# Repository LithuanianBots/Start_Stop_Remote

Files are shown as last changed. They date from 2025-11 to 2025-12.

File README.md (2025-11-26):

# Start_Stop_Remote

Start_Stop_Remote is a compact infrared remote designed for use with the MINI SUMO kit mainboard. It provides a small, robust controller for starting and stopping matches and is built with readily-available components to make assembly and sourcing easy.

Key features
- Remote uses IR SMD LEDs for a low-profile, reliable IR transmitter.
- Remote has additional IR LED footprints for standard 5 mm LEDs if you prefer through-hole components.
- PCB size: 80 mm x 40 mm — compact and easy to fit in a small enclosure.
- All free ATmega328 pins are routed to accessible solder pads so you can expand or repurpose the board.
- Most parts come from the LCSC basic parts library to simplify procurement.

Files and docs
- Full schematic and 3d files are available in the Docs folder:
  - Docs/Start_Stop_Remote.pdf
  - Docs/Start_Stop_Remote.step

Gallery (Top and Bottom views)
| TOP view | BOT view |
|---|---|
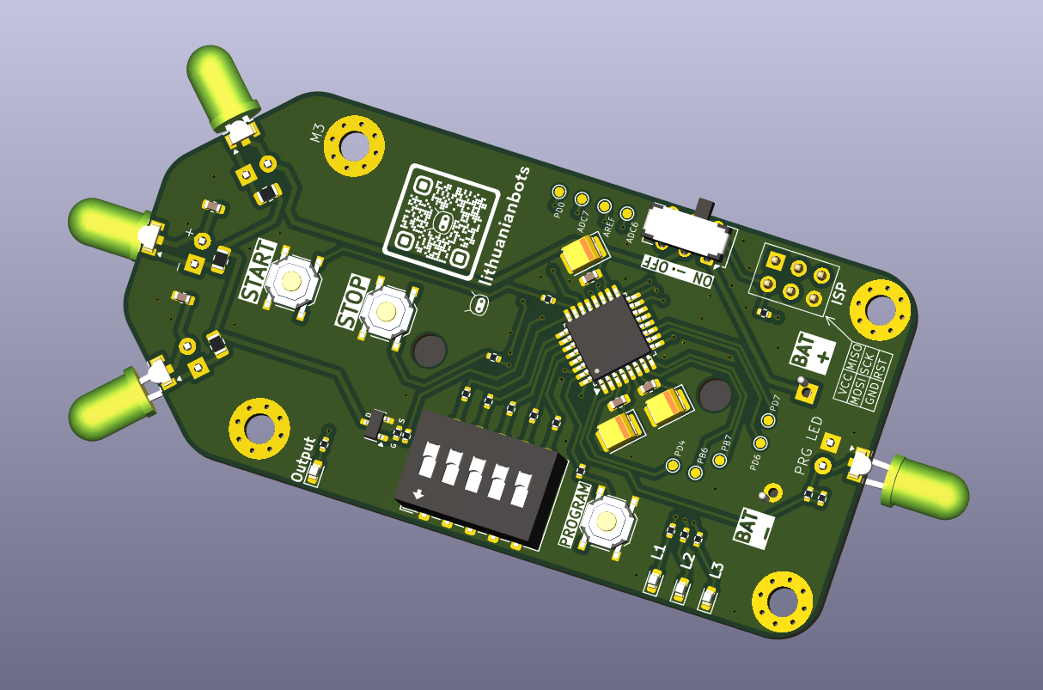
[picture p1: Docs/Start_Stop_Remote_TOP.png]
Start_Stop_Remote TOP
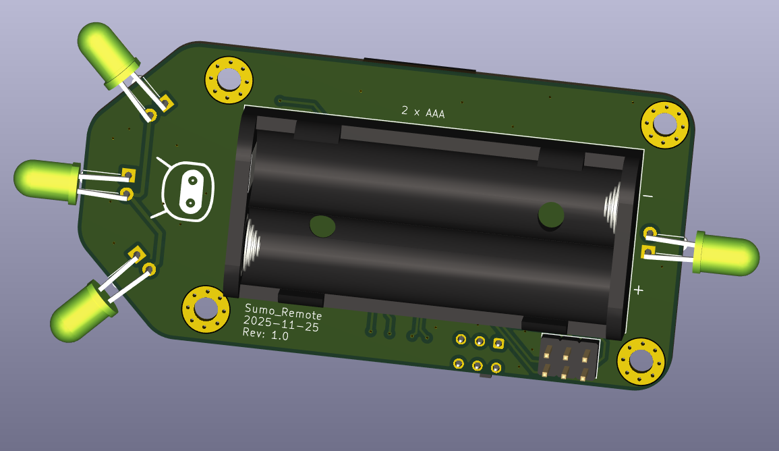
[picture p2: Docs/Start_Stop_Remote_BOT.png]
Start_Stop_Remote BOT
|  |  |

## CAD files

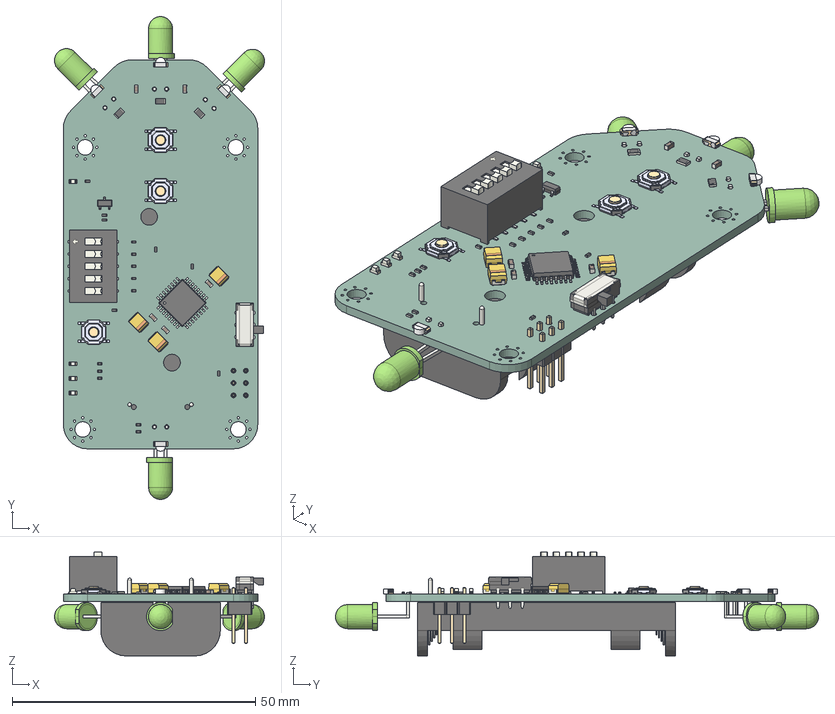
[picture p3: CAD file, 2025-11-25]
Docs/Start_Stop_Remote.step
43.2 x 99.3 x 21.4 mm
LTST-S326KGJRKT x 4
R_0402_1005Metric x 17
TS-1187A-B-A-B x 3
CP_EIA-3528-21_Kemet-B x 3
SW_DIP_SPSTx05_Slide_9.78x14.88mm_W8.61mm_P2.54mm
LED_0603_1608Metric x 4
SW_CK_JS202011AQN_DPDT_Angled
C_0603_1608Metric x 5
R_0805_2012Metric x 3
LQFP-32_7x7mm_P0.8mm
SOT-23
LED_D5.0mm_Horizontal_O6.35mm_Z3.0mm x 4
PinHeader_2x03_P2.54mm_Vertical
BatteryHolder_Keystone_2468_2xAAA
Start_Stop_Remote_PCB

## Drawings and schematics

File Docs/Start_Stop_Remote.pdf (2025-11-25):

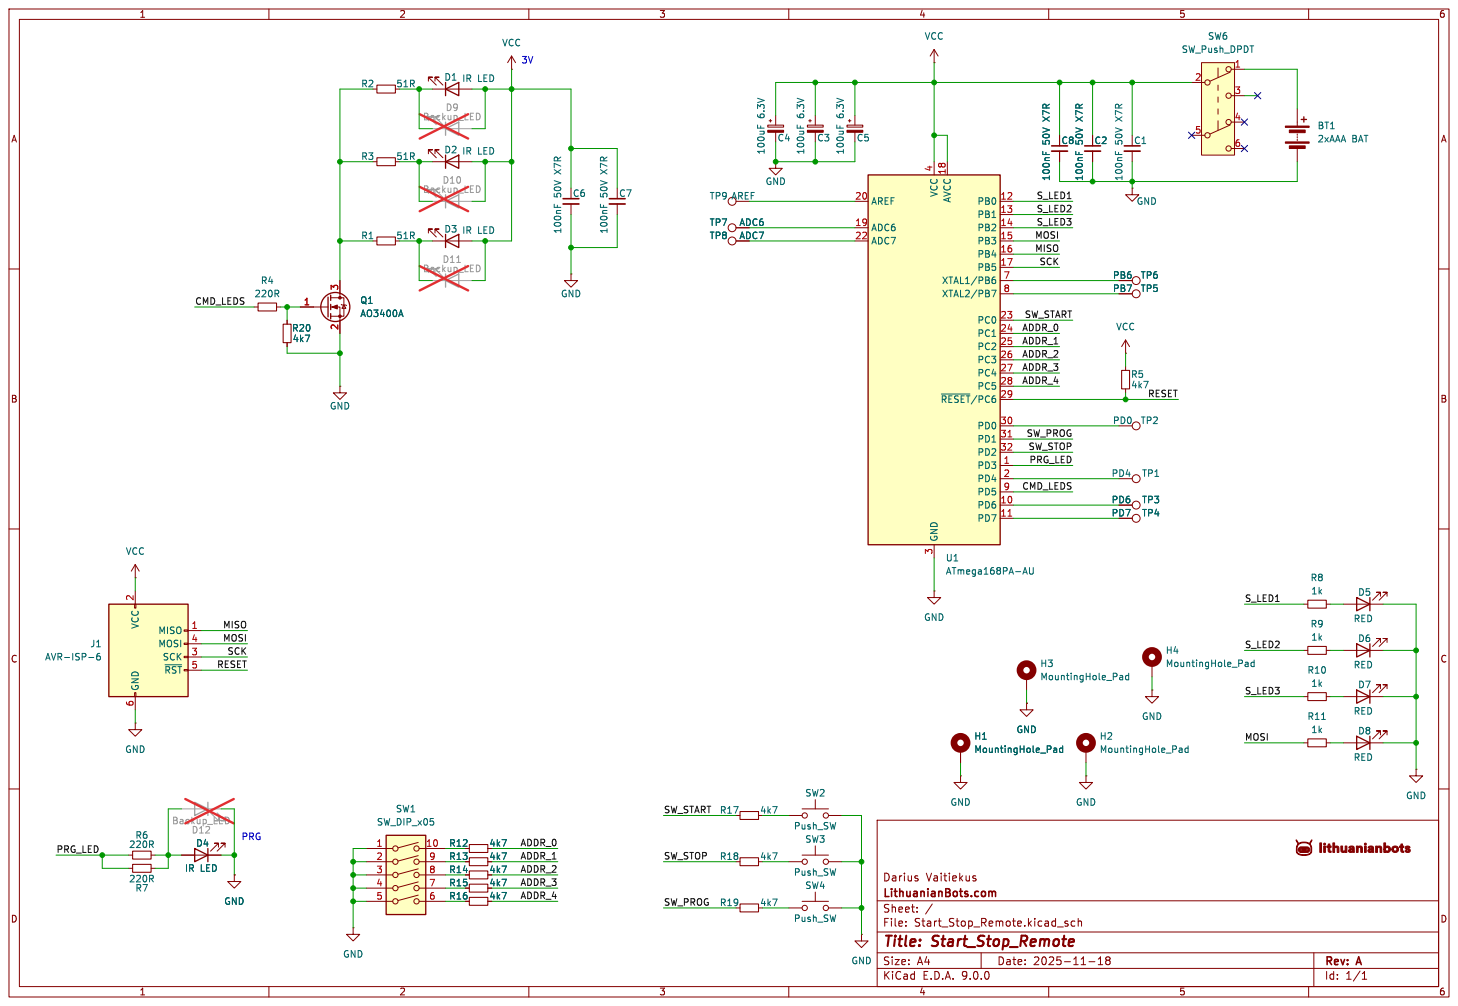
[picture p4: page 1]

6 MISO 1 MOSI 4 SCK 3 ~{RST}5

File: Start_Stop_Remote.kicad_sch Sheet: / LithuanianBots.com

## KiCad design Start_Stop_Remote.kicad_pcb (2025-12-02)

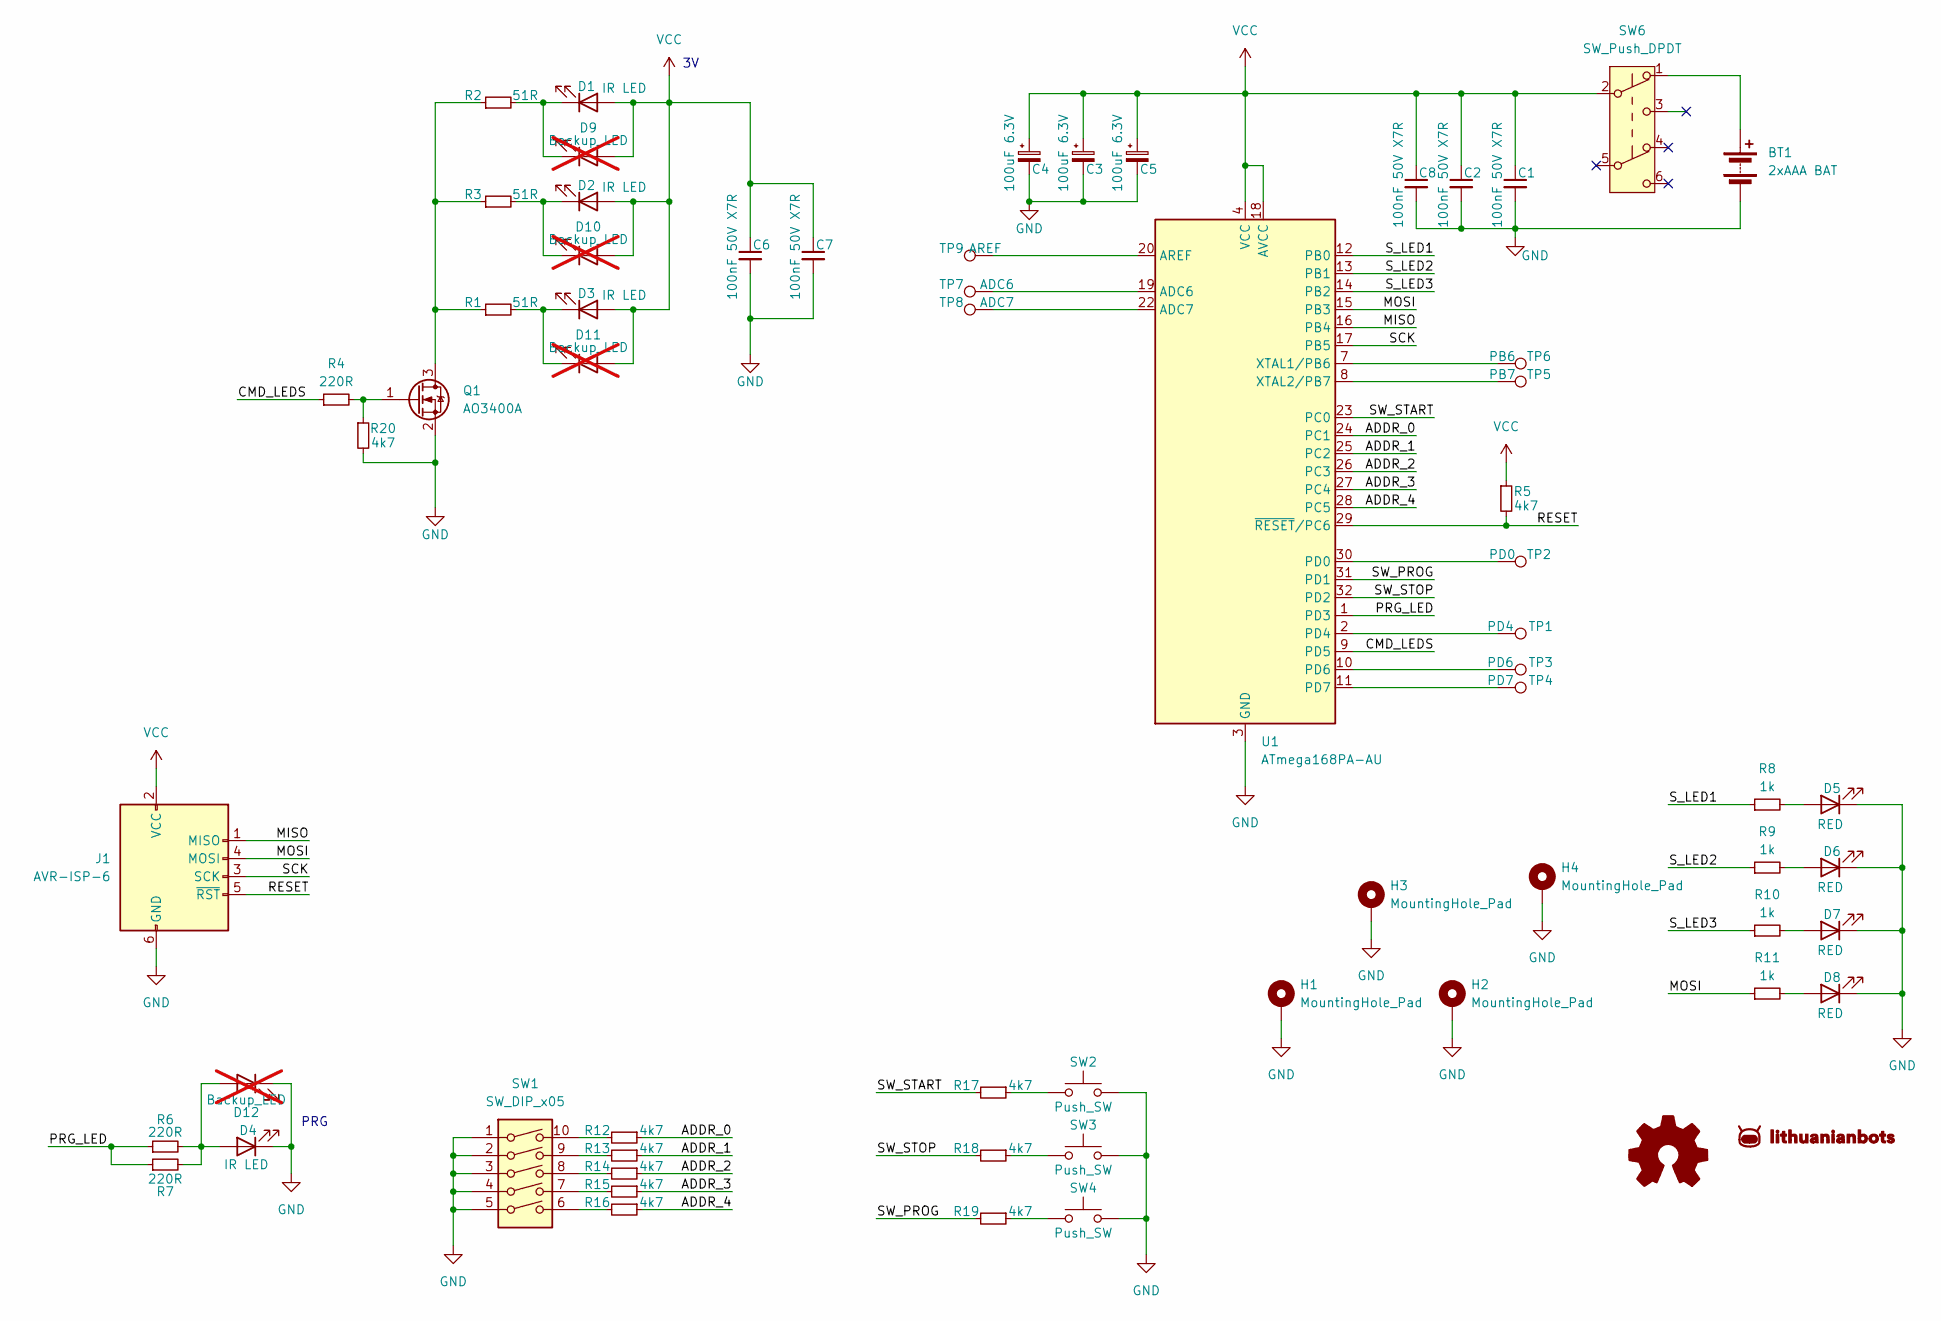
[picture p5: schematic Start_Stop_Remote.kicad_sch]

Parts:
BT1: 2xAAA BAT; BatteryHolder_-AAA-A1AJ020; LCSC C5290191
C1, C2, C6, C7, C8: 100nF 50V X7R; C_0603_1608Metric; LCSC C14663
C3, C4, C5: 100uF 6.3V; CP_EIA-3528-21_Kemet-B; LCSC C16133
D1, D2, D3, D4: IR LED; LED_LiteOn_LTST-S326; LCSC C5349963
D5, D6, D7, D8: RED; LED_0603_1608Metric; LCSC C2286
D9, D10, D11, D12: Backup_LED; LED_D5.0mm_Horizontal_O6.35mm_Z3.0mm; not fitted
H1, H2, H3, H4: MountingHole_Pad; MountingHole_3.2mm_M3_Pad_Via
J1: AVR-ISP-6; PinHeader_2x03_P2.54mm_Vertical; LCSC C65114
Q1: AO3400A; SOT-23; LCSC C20917
R1, R2, R3: 51R; R_0805_2012Metric; LCSC C17738
R4, R6, R7: 220R; R_0402_1005Metric; LCSC C25091
R5, R12, R13, R14, R15, R16, R17, R18, R19, R20: 4k7; R_0402_1005Metric; LCSC C25900
R8, R9, R10, R11: 1k; R_0402_1005Metric; LCSC C11702
SW1: SW_DIP_x05; SW_DIP_SPSTx05_Slide_9.78x14.88mm_W8.61mm_P2.54mm; LCSC C54951
SW2, SW3, SW4: Push_SW; SW_Push_1P1T_XKB_TS-1187A; LCSC C318884
SW6: SW_Push_DPDT; SW_CK_JS202011AQN_DPDT_Angled; LCSC C7507433
TP1: PD4; TestPoint_Pad_D1.0mm
TP2: PD0; TestPoint_Pad_D1.0mm
TP3: PD6; TestPoint_Pad_D1.0mm
TP4: PD7; TestPoint_Pad_D1.0mm
TP5: PB7; TestPoint_Pad_D1.0mm
TP6: PB6; TestPoint_Pad_D1.0mm
TP7: ADC6; TestPoint_Pad_D1.0mm
TP8: ADC7; TestPoint_Pad_D1.0mm
TP9: AREF; TestPoint_Pad_D1.0mm
U1: ATmega168PA-AU; LQFP-32_7x7mm_P0.8mm; LCSC C8728

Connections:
/ADDR_0: R12.1, U1.24 (PC1)
/ADDR_1: R13.1, U1.25 (PC2)
/ADDR_2: R14.1, U1.26 (PC3)
/ADDR_3: R15.1, U1.27 (PC4)
/ADDR_4: R16.1, U1.28 (PC5)
/CMD_LEDS: R4.1, U1.9 (PD5)
/MISO: J1.1 (MISO), U1.16 (PB4)
/MOSI: J1.4 (MOSI), R11.1, U1.15 (PB3)
/PRG_LED: R6.1, R7.1, U1.1 (PD3)
/RESET: J1.5 (~RST), R5.2, U1.29 (~RESET/PC6)
/SCK: J1.3 (SCK), U1.17 (PB5)
/SW_PROG: R19.2, U1.31 (PD1)
/SW_START: R17.2, U1.23 (PC0)
/SW_STOP: R18.2, U1.32 (PD2)
/S_LED1: R8.1, U1.12 (PB0)
/S_LED2: R9.1, U1.13 (PB1)
/S_LED3: R10.1, U1.14 (PB2)
GND: BT1.2 (-), C1.2, C2.2, C3.2, C4.2, C5.2, C6.2, C7.2, C8.2, D4.1 (K), D5.1 (K), D6.1 (K), D7.1 (K), D8.1 (K), D12.1 (K), H1.1, H2.1, H3.1, H4.1, J1.6 (GND), Q1.2 (S), R20.2, SW1.1, SW1.2, SW1.3, SW1.4, SW1.5, SW2.2, SW3.2, SW4.2, U1.3 (GND), U1.5 (GND), U1.21 (GND)
unnamed: BT1.1 (+), SW6.1 (A)
unnamed: D1.1 (K), D9.1 (K), R2.2
unnamed: D5.2 (A), R8.2
unnamed: D6.2 (A), R9.2
unnamed: D7.2 (A), R10.2
unnamed: D8.2 (A), R11.2
unnamed: D2.1 (K), D10.1 (K), R3.2
unnamed: D3.1 (K), D11.1 (K), R1.2
unnamed: D4.2 (A), D12.2 (A), R6.2, R7.2
unnamed: Q1.3 (D), R1.1, R2.1, R3.1
unnamed: Q1.1 (G), R4.2, R20.1
unnamed: R12.2, SW1.10
unnamed: R13.2, SW1.9
unnamed: R14.2, SW1.8
unnamed: R15.2, SW1.7
unnamed: R16.2, SW1.6
unnamed: R17.1, SW2.1
unnamed: R18.1, SW3.1
unnamed: R19.1, SW4.1
unnamed: TP7.1, U1.19 (ADC6)
unnamed: TP8.1, U1.22 (ADC7)
unnamed: TP9.1, U1.20 (AREF)
unnamed: TP2.1, U1.30 (PD0)
unnamed: TP1.1, U1.2 (PD4)
unnamed: TP3.1, U1.10 (PD6)
unnamed: TP4.1, U1.11 (PD7)
unnamed: TP6.1, U1.7 (XTAL1/PB6)
unnamed: TP5.1, U1.8 (XTAL2/PB7)
VCC: C1.1, C2.1, C3.1, C4.1, C5.1, C6.1, C7.1, C8.1, D1.2 (A), D2.2 (A), D3.2 (A), D9.2 (A), D10.2 (A), D11.2 (A), J1.2 (VCC), R5.1, SW6.2 (B), U1.4 (VCC), U1.6 (VCC), U1.18 (AVCC)

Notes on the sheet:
PRG

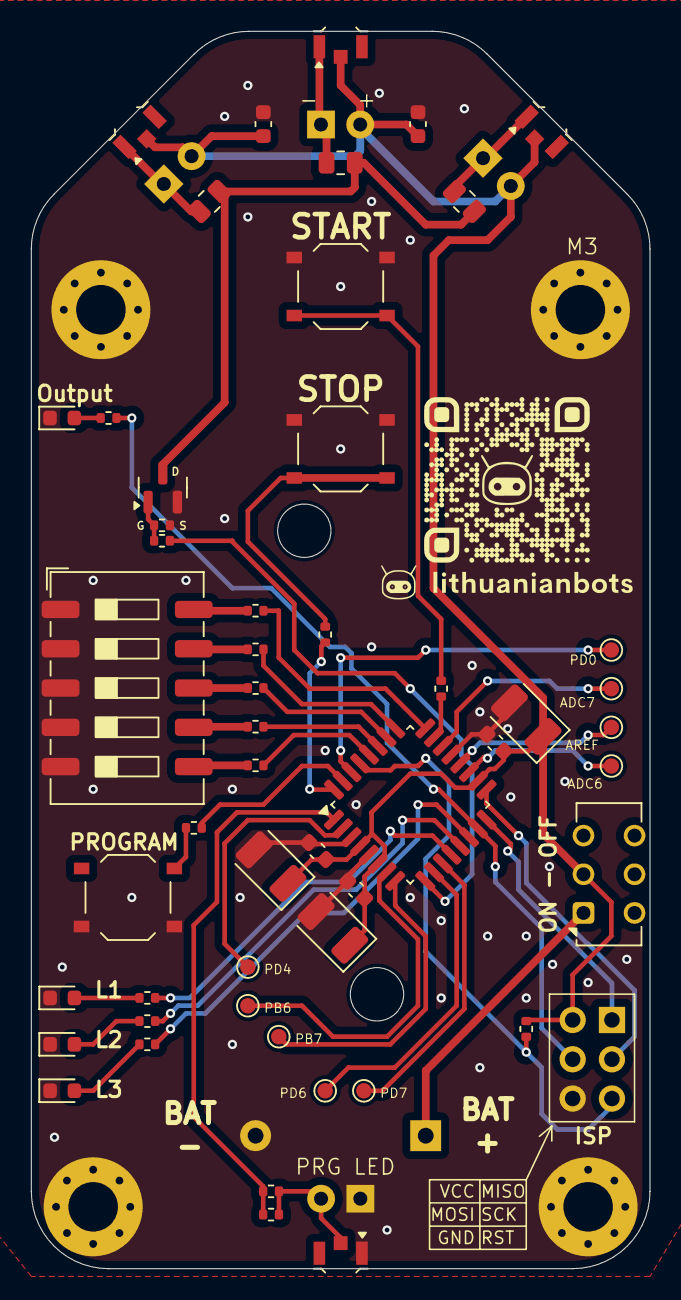
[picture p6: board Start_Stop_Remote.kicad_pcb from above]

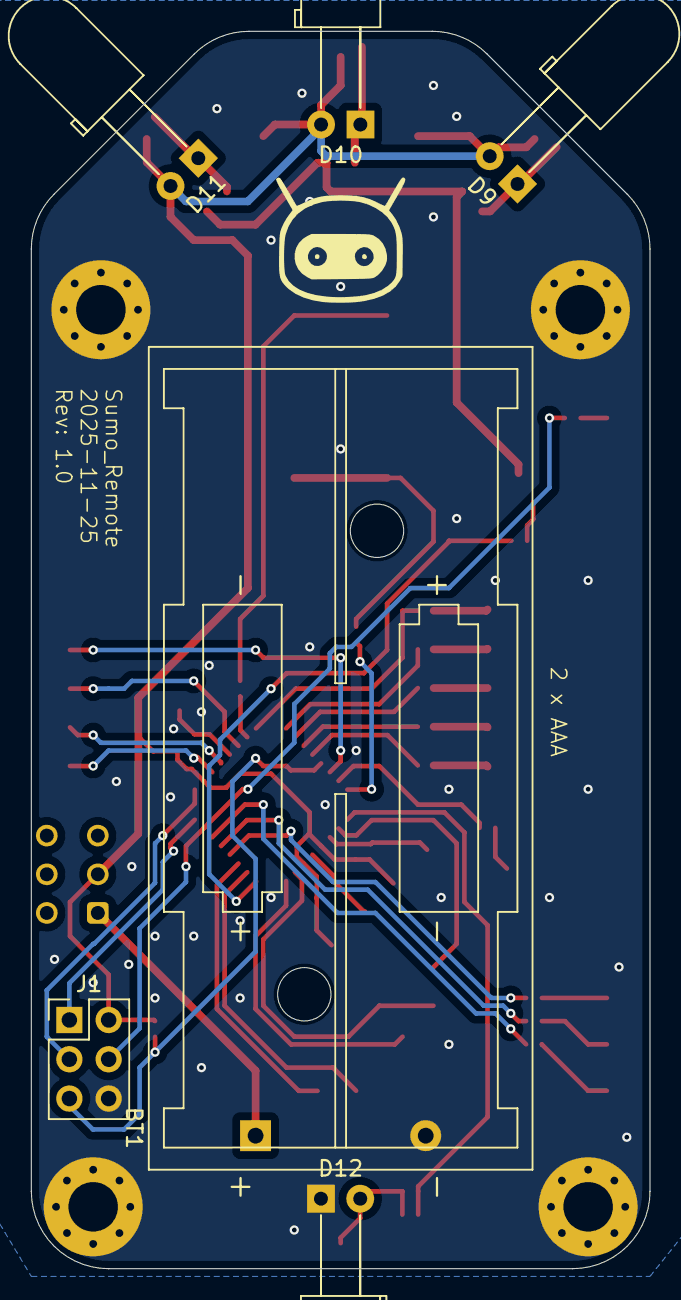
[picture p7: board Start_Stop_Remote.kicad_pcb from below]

Board: 2 copper layers, 40.0 x 80.0 mm, 62 parts (6 on the bottom side), 47 nets.

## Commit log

2025-11-25 Added extra files
    Couple of pictures
    And schematic
    [Start_Stop_Remote.kicad_pcb, Start_Stop_Remote.step]
2025-11-26 DRC fixes
    One trace routing fix near program button.
    [Start_Stop_Remote-CuBottom.gbr, Start_Stop_Remote-CuTop.gbr, Start_Stop_Remote-EdgeCuts.gbr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]
2025-12-02 QR Code Update
    Old QR code was linked to an external website, that has paid service. New one - just links to https://lithuanianbots.com
    Library footprint updated as well.
    [Start_Stop_Remote-CuBottom.gbr, Start_Stop_Remote-CuTop.gbr, Start_Stop_Remote-EdgeCuts.gbr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]
